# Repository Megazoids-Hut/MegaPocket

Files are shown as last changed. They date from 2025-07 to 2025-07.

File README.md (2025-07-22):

# MegaPocket

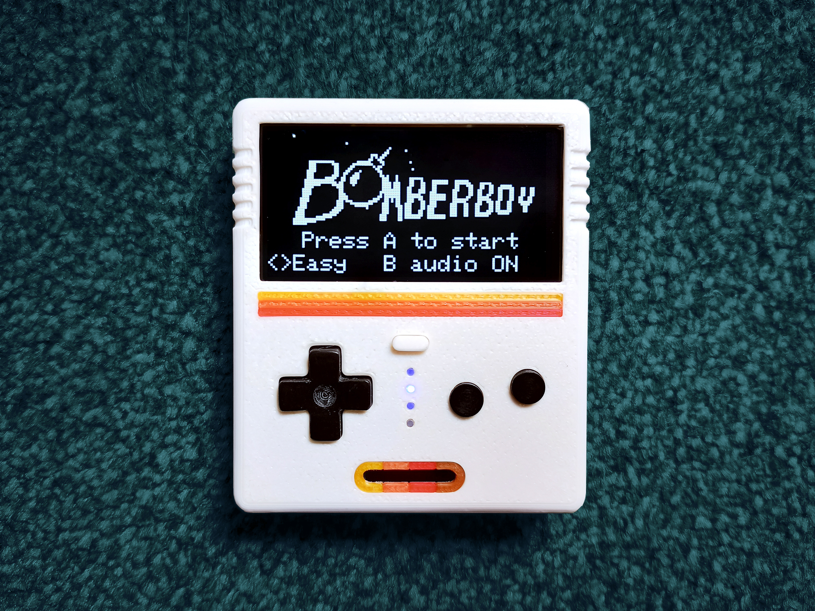
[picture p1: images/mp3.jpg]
mp3


MegaPocket is an ATmega32U4 based DIY gaming handheld, with 2.42 inch OLED display. Arduboy game compatible.

I wanted the MegaPocket project files accessable on GitHub. The project is posted on the following sites, which will have full build instructions :  
https://www.hackster.io/megazoid/megapocket-d62f25  
https://www.instructables.com/MegaPocket  

> YouTube video on MegaPocket : https://www.youtube.com/watch?v=42iLDeShEv4
  
________________________________________________________________  
  
# Supplies

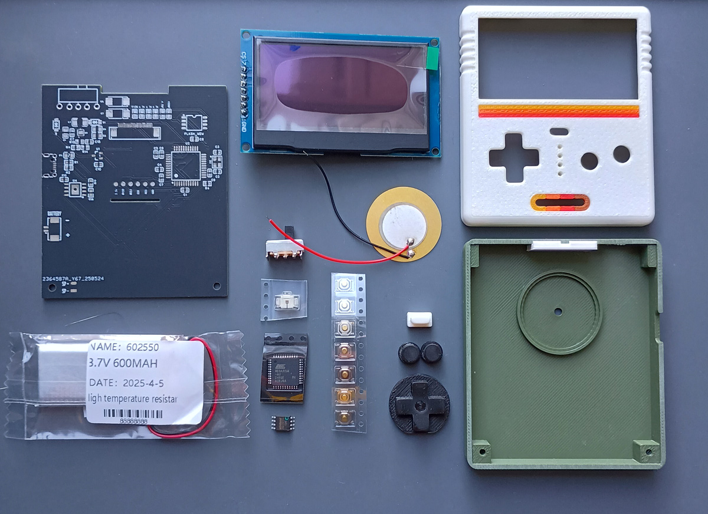
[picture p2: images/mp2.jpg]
mp2


### Parts
1 x 2.42 Inch 128x64 OLED Display Module SSD1309 SPI interface White [AliExpress](https://vi.aliexpress.com/item/1005006100836064.html)  
1 x 602550 Polymer Lithium Battery [AliExpress](https://vi.aliexpress.com/item/1005006898814536.html)  
1 x Piezoelectric Piezo Ceramic Wafer 18mm [AliExpress](https://vi.aliexpress.com/item/1005007163777390.html)  
1 x W25Q128FVSG 128Mb/16MB flash chip [AliExpress](https://vi.aliexpress.com/item/32635057471.html)  
2 x 0603 LEDs 2 Colours [AliExpress](https://vi.aliexpress.com/item/1005005431944057.html)  
4 x M2 x 16mm Flat Head Hex Socket Screws [Amazon](https://www.amazon.co.uk/FandWay-Countersunk-Machine-Washers-Assortment/dp/B0B7JLDV6V/?th=1)  
1 x Silicone Rubber Sheet Thickness 0.5 [AliExpress](https://vi.aliexpress.com/item/1005006921978058.html)  
1 x Clear Grass Trimmer Line [Amazon](https://www.amazon.co.uk/Oregon-69-482-CL-Round-Strimmer-Trimmers/dp/B07SQKP6B3/)  

... and a huge list of parts from LCSC.com that you are going to have to get from the [BOM file ](https://github.com/Megazoids-Hut/MegaPocket/tree/main/bom).  

### Hand Tools & Equipment  

Soldering iron + Solder Wire 40/60 + Solder Flux + Isopropyl  
A Hot Plate and 3d printer  
Watch Makers Loupe or other Magnification  
Kapton tape + Hot Glue + Sand Paper + Double Sided Tape   

The custom PCB can be ordered from a PCB fabrication manufacturer Like JLBPCB : [Gerber File Zip](https://github.com/Megazoids-Hut/MegaPocket/blob/main/gerber/gerber_pcb_megapocket.zip) (Use default PCB board settings. 1.6mm thickness etc. Just upload the gerber zip and order)

________________________________________________________________  
  
# Story

MegaPocket is the third in my series of DIY handheld gaming devices that share the same form factor. Powered by an ATmega32U4, it's a "big screen" Arduboy® game compatible handheld. The 12V boost circuit needed to drive the 2.42 inch OLED has been incorporated on the PCB. It is somewhat unique in this regard. The project's reception was best discribed as "flat". 5 years too late...  

I spent an age trying to find a case style that I liked, but finally settled for some retro stripes. It's looks a little 70's to me. Apart from expecting the paper thin screen to snap at any point, it was easy enough to put together. Some small RGB LED light bleed issues persist, but I'm happy with the results. 

It will play all the games that were designed for Arduboy®. 

<b>Licensing</b>: My PCB files and STLs are released under [The Unlicense](https://unlicense.org/). Everything else retains the licenses assigned by their creators. I take no responsibility for anything. I am not linked in any way with the open-source gaming console [Picopad.](https://picopad.eu/en/)

<b>Arduboy® is a registered trademark of Arduboy, Inc. This project is not affiliated with, authorized by, endorsed by, or connected to Arduboy, Inc. in any way.</b>

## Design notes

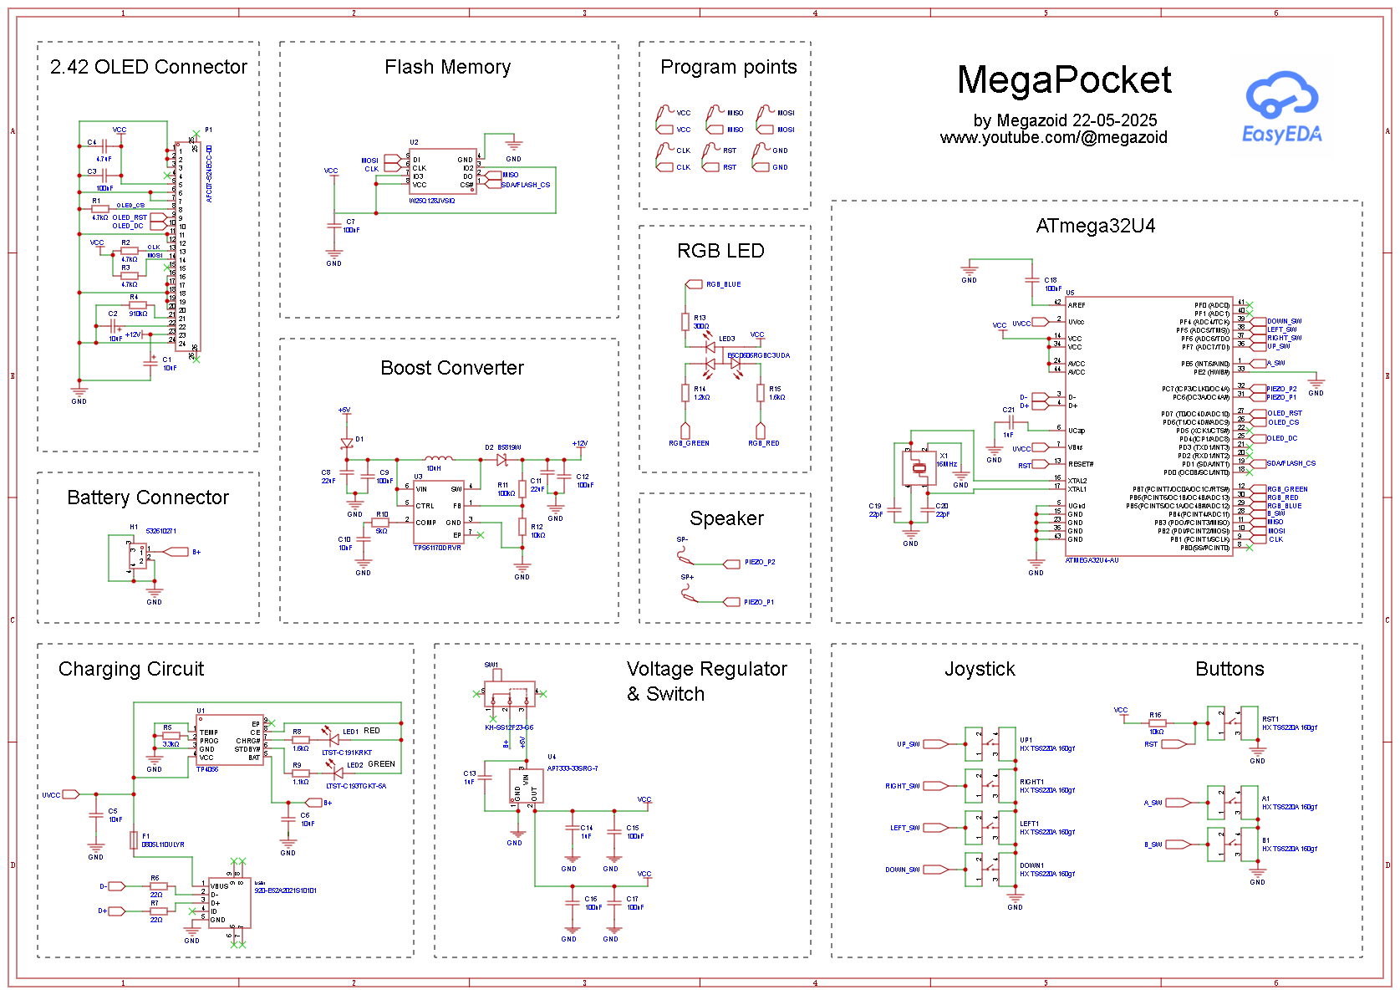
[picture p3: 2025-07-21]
schematic/SCH_Schematic1_1-P1_2025-07-21.png

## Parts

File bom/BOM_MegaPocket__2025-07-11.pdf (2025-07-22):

No. | Quantity | Comment | Designator | Footprint | Value | Manufacturer Part | Manufacturer | Supplier Part | Supplier
1 | 7 | HX TS5220A 160gf | A1,B1,DOWN1,LEFT1,RIGHT1,RST1,UP1 SW-SMD_4P-L5.2-W5.2-P3.70-LS6.4 | | | HX TS5220A 160gf | hanxia(韩下) | C5340185 | LCSC
2 | 2 | 10uF | C1,C2 | CASE-C_6032 | 10uF | 593D106X9025C2TE3 | VISHAY(威世) | C132690 | LCSC
3 | 7 | 100nF | C3,C7,C9,C15,C16,C17,C18C0603 | | 100nF | CC0603KRX7R9BB104 | YAGEO(国巨) | C14663 | LCSC
4 | 1 | 4.7uF | C4 | C0603 | 4.7uF | CL10A475KO8NNNC | SAMSUNG(三星) | C19666 | LCSC
5 | 2 | 10uF | C5,C6 | C0603 | 10uF | CL10A106MQ8NNNC | SAMSUNG(三星) | C1691 | LCSC
6 | 2 | 22uF | C8,C11 | C0805 | 22uF | GRM21BR61E226ME44L | muRata(村田) | C86816 | LCSC
7 | 1 | 10nF | C10 | C0603 | 10nF | CC0603KRX7R9BB103 | YAGEO(国巨) | C100042 | LCSC
8 | 1 | 100nF | C12 | C0805 | 100nF | GCM21BR91H104KA37L | muRata(村田) | C161269 | LCSC
9 | 3 | 1uF | C13,C14,C21 | C0603 | 1uF | CL10A105KB8NNNC | SAMSUNG(三星) | C15849 | LCSC
10 | 2 | 22pF | C19,C20 | C0603 | 22pF | CL10C220JB8NNNC | SAMSUNG(三星) | C1653 | LCSC
11 | 1 | CLK | CLK | Test-Point-0.5mm
12 | 2 | B5819W | D1,D2 | SOD-123_L2.8-W1.8-LS3.7-FD-1 | | B5819W | FUXINSEMI(富芯森美) | C908224 | LCSC
13 | 1 | 0805L110ULYR | F1 | F0805 | | 0805L110ULYR | Littelfuse(美国力特) | C468888 | LCSC
14 | 1 | GND | GND | Test-Point-0.5mm
15 | 1 | 532610271 | H1 | CONN-SMD_532610271 | | 532610271 | MOLEX | C177225 | LCSC
16 | 1 | 10uH | L3 | IND-SMD_L3.2-W2.5 | 10uH | SCW3225H100KTT | Sunltech(顺磁) | C2842780 | LCSC
17 | 1 | LTST-C191KRKT | LED1 | LED0603-RD | | LTST-C191KRKT | LITEON(光宝) | C125099 | LCSC
18 | 1 | LTST-C193TGKT-5A | LED2 | LED0603-RD | | LTST-C193TGKT-5A | LITEON(光宝) | C12065 | LCSC
19 | 1 | E6C0606RGBC3UDA | LED3 | LED-ARRAY-SMD_4P-L1.6-W1.6_SY-PB2333RGBC-010F E6C0606RGBC3UDA | | | ekinglux(亿晶源) | C375569 | LCSC
20 | 1 | MISO | MISO | Test-Point-0.5mm
21 | 1 | MOSI | MOSI | Test-Point-0.5mm
22 | 1 | AFC07-S24ECC-00 | P1 | FPC-SMD_24P-L17.5-W5.4-P0.50 | | AFC07-S24ECC-00 | JS(钜硕电子) | C11092 | LCSC
23 | 3 | 4.7kΩ | R1,R2,R3 | R0603 | 4.7kΩ | 0603WAF4701T5E | UNI-ROYAL(厚声) | C23162 | LCSC
24 | 1 | 910kΩ | R4 | R0603 | 910kΩ | 0603WAF9103T5E | UNI-ROYAL(厚声) | C23263 | LCSC
25 | 1 | 3.3kΩ | R5 | R0603 | 3.3kΩ | 0603WAF3301T5E | UNI-ROYAL(厚声) | C22978 | LCSC
26 | 2 | 22Ω | R6,R7 | R0603 | 22Ω | 0603WAF220JT5E | UNI-ROYAL(厚声) | C23345 | LCSC
27 | 2 | 1.6kΩ | R8,R15 | R0603 | 1.6kΩ | 0603WAF1601T5E | UNI-ROYAL(厚声) | C22847 | LCSC
28 | 1 | 1.1kΩ | R9 | R0603 | 1.1kΩ | 0603WAF1101T5E | UNI-ROYAL(厚声) | C22764 | LCSC
29 | 1 | 5kΩ | R10 | R0603 | 5kΩ | RTT035001FTP | RALEC(旺诠) | C166926 | LCSC
30 | 1 | 100kΩ | R11 | R0603 | 100kΩ | 0603WAF1003T5E | UNI-ROYAL(厚声) | C25803 | LCSC
31 | 2 | 10kΩ | R12,R16 | R0603 | 10kΩ | 0603WAF1002T5E | UNI-ROYAL(厚声) | C25804 | LCSC
32 | 1 | 300Ω | R13 | R0603 | 300Ω | 0603WAF3000T5E | UNI-ROYAL(厚声) | C23025 | LCSC
33 | 1 | 1.2kΩ | R14 | R0603 | 1.2kΩ | 0603WAF1201T5E | UNI-ROYAL(厚声) | C22765 | LCSC
34 | 1 | RST | RST | Test-Point-0.5mm
35 | 2 | Test-Point | SP+,SP- | Test-Point-0.5mm
36 | 1 | KH-SS12F23-G6 | SW1 | SW-TH_KH-SS12F23-G6 | | KH-SS12F23-G6 | kinghelm(金航标) | C5274466 | LCSC
37 | 1 | TP4056 | U1 | ESOP-8_L4.9-W3.9-P1.27-LS6.0-BL-EP | | TP4056 | UMW(友台半导体) | C725790 | LCSC
38 | 1 | W25Q128JVSIQ | U2 | SOIC-8_L5.3-W5.3-P1.27-LS8.0-BL | | W25Q128JVSIQ | WINBOND(华邦) | C97521 | LCSC
39 | 1 | TPS61170DRVR | U3 | QFN-6_L2.0-W2.0-P0.65-TL-EP | | TPS61170DRVR | TI(德州仪器) | C15163 | LCSC
40 | 1 | AP7333-33SRG-7 | U4 | SOT-23-3_L2.9-W1.3-P1.90-LS2.4-BR | | AP7333-33SRG-7 | DIODES(美台) | C150745 | LCSC
41 | 1 | ATMEGA32U4-AU | U5 | QFP-44_L10.0-W10.0-P0.80-LS13.2-BL | | ATMEGA32U4-AU | MICROCHIP(美国微芯) | C44854 | LCSC
42 | 1 | 920-E52A2021S10101 | USB1 | MICRO-USB_MICRO-USB-30 | | 920-E52A2021S10101 | 精拓金 | C40946 | LCSC
43 | 1 | VCC | VCC | Test-Point-0.5mm
44 | 1 | 16MHz | X1 | CRYSTAL-SMD_4P-L3.2-W2.5-BL 16MHz | | TAXM16M4RDBCCT2T | YJX(雅晶鑫) | C164044 | LCSC

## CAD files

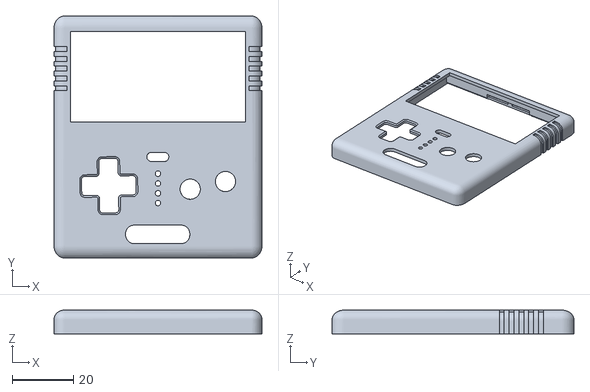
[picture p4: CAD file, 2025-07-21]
stl/Front.stl
67.8 x 78.8 x 7.78

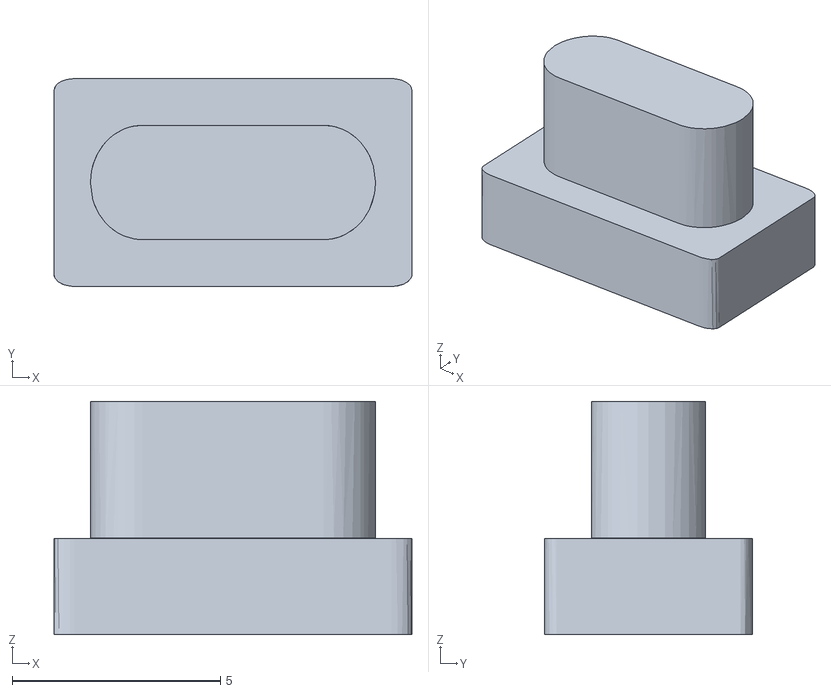
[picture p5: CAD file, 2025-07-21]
stl/Reset.stl
8.60 x 5.00 x 5.60

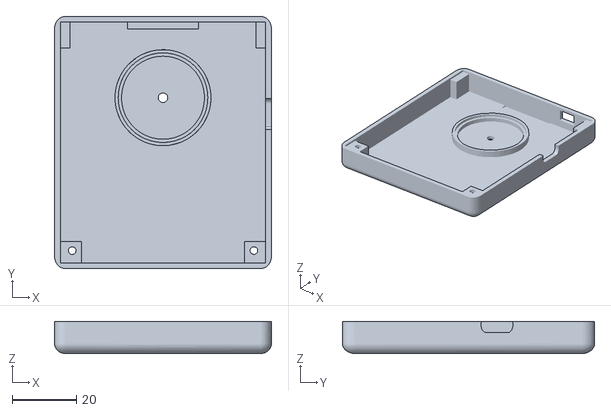
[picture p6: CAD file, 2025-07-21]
stl/Back.stl
67.8 x 78.8 x 10.0

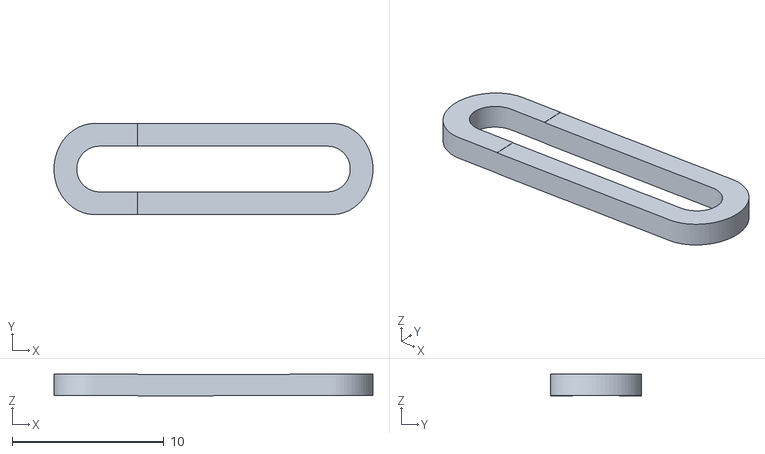
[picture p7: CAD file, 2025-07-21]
stl/Grill.stl
21.0 x 6.00 x 1.42

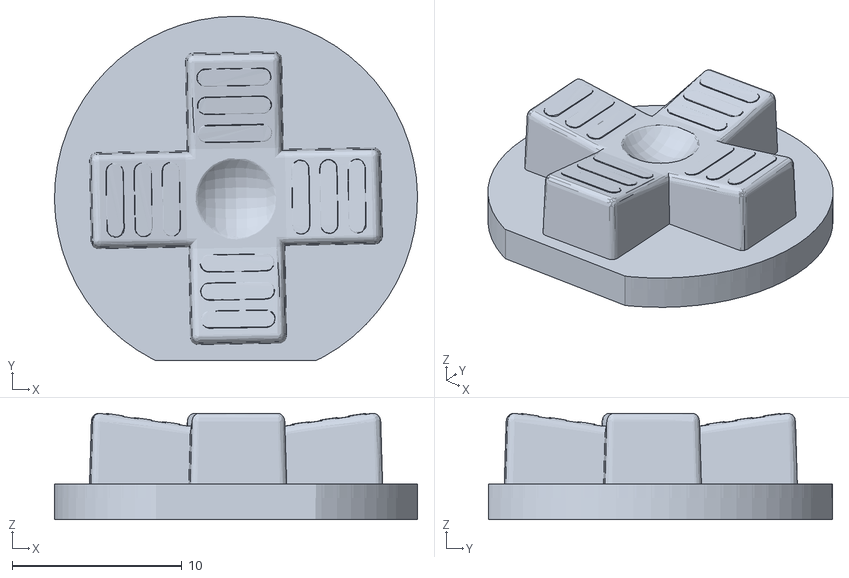
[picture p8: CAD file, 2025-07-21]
stl/Thumb.stl
21.4 x 20.3 x 6.26

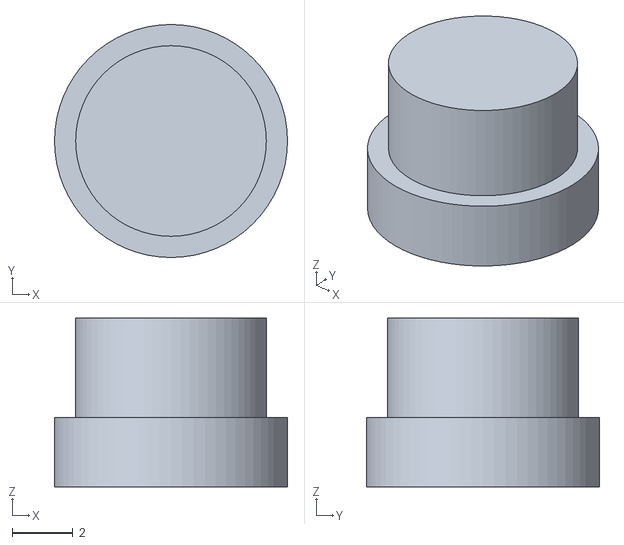
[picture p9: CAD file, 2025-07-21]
stl/Buttons.stl
7.70 x 7.70 x 5.58

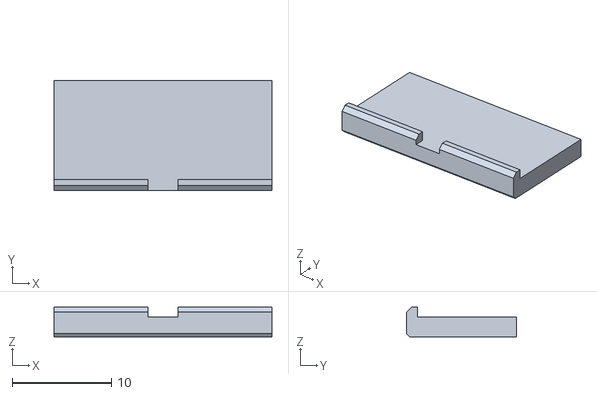
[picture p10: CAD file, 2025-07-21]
stl/Clip.stl
22.0 x 11.1 x 3.00

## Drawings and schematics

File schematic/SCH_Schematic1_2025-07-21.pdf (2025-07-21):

# 2.42 OLED Connector

# ATmega32U4

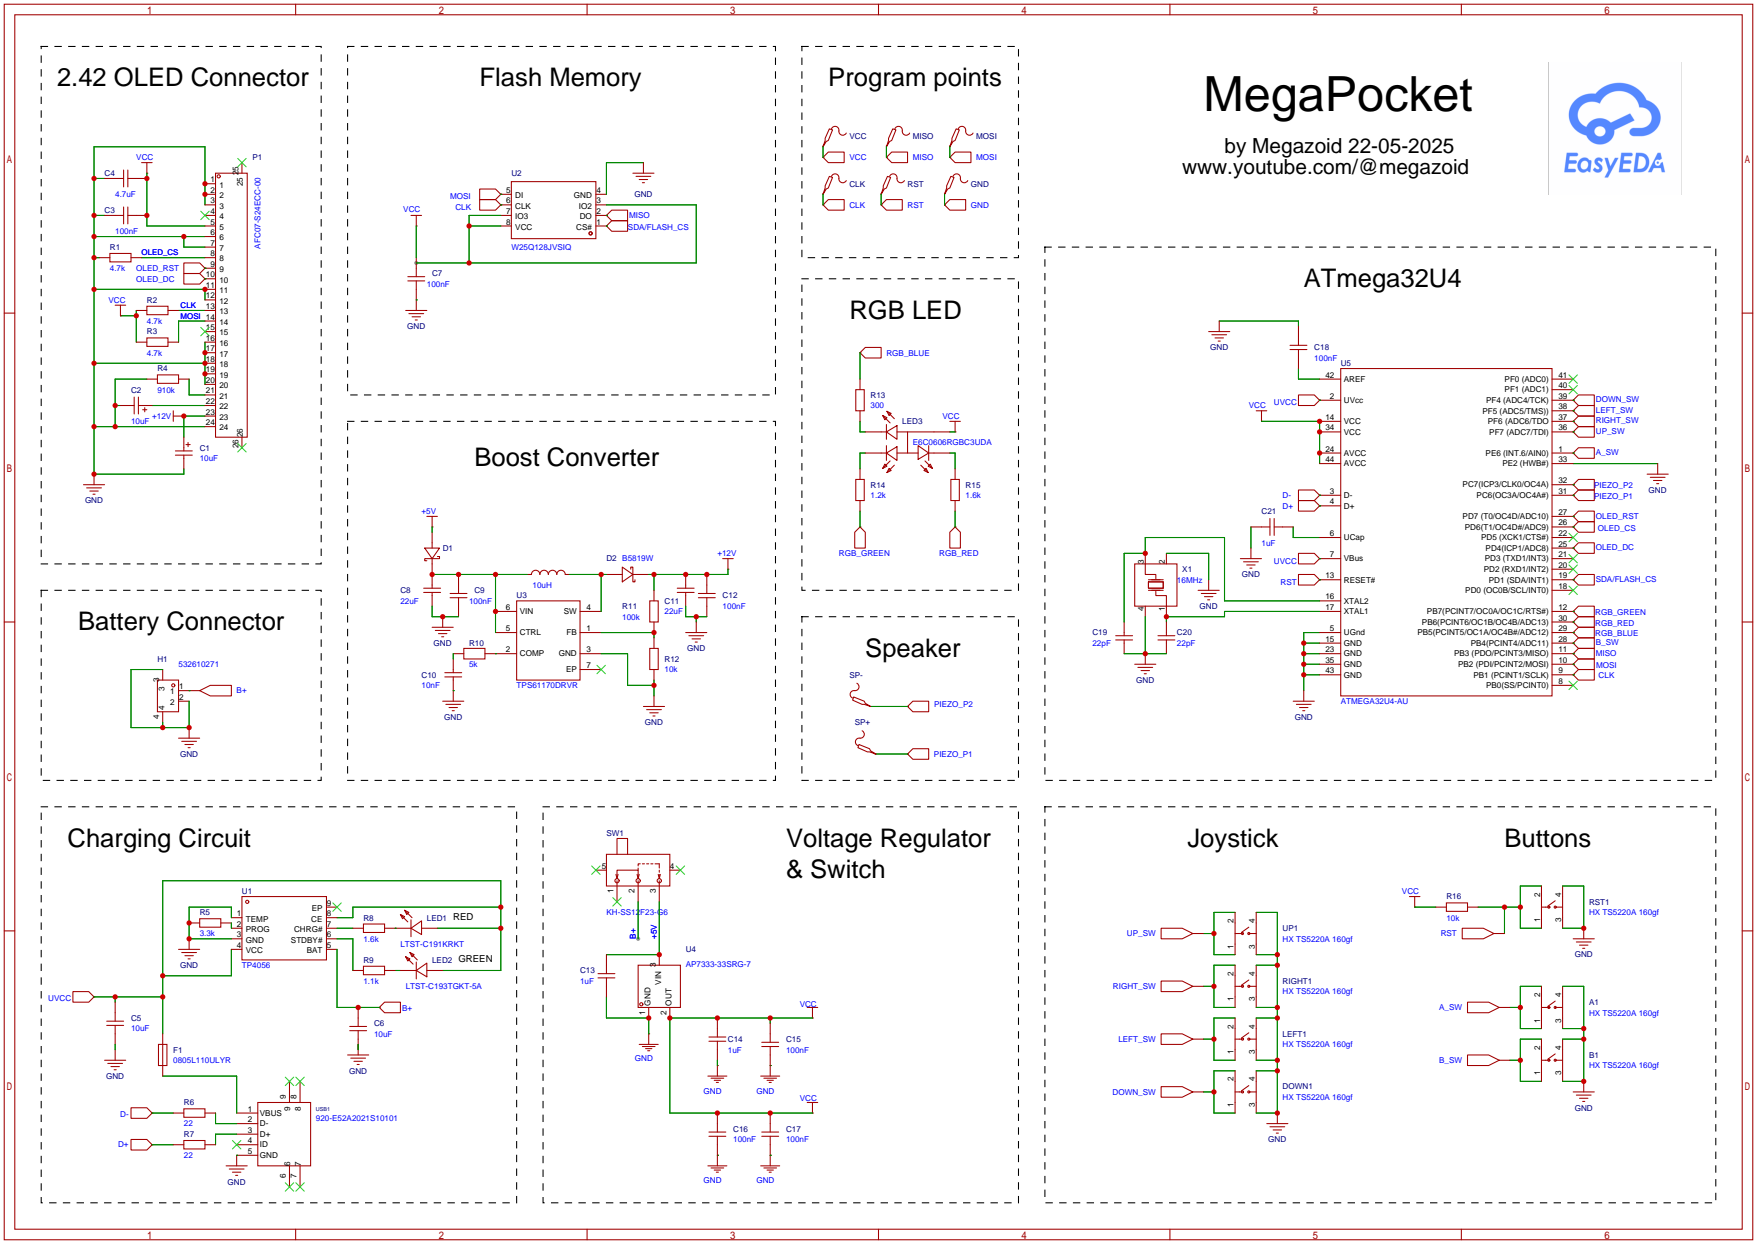
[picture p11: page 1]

by Megazoid 22-05-2025
www.youtube.com/@megazoid
